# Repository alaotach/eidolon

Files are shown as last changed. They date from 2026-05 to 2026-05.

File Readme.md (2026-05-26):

# Euphoria

## Project Overview
Euphoria is a 3d holographic display for your setup and you can display whatever you want on it from anywhere in the world using the WiFi.

## Why I Built This
I was looking to build something, i searched for many ideas and I had liked a women safety device at first but that didn't make some sense so i started looking again and then i found something on my youtube recommendation it was titled "real holographic displays" and it showed a similar holographic display using the pepper's ghost technique and I really liked the idea and I wanted it on my desk too so i started building it immediately.

EUPHORIA-zine

## What's Inside This Folder
**PCB & Hardware Files:**
- `hardware/gerbers/` - All Gerber files for PCB manufacturing (e.g., `hologram-F_Cu.gbr`, `hologram-B_Cu.gbr`, etc.)
- `hardware/pcbs/hologram.kicad_pcb` - The main PCB layout file.
Screenshot_2026-05-20_085501-removebg-preview

- `hardware/pcbs/hologram.kicad_sch` - The main schematic.
- `hardware/pcbs/hologram.kicad_pro` - KiCad project file for editing.
- `hardware/fab/outputs/3d/updated-pcb.stl` - 3D model of the PCB.
PCB-F
PCB-B

**Firmware:**
  - `firmware/eidolon/` - All firmware source code.
	- `include/` - Header files.
**3D Case Files:**
- `hardware/fab/outputs/3d/updated-pcb.f3d` - 3D models for the PCB.
- `hardware/fab/outputs/3d/eldolon-case.stl` - 3D model of the case.
case
case1

**Misc Files:**
- `hardware/fab/outputs/bom/BOM.csv` - BOM.

## The Files You Actually Need
**To Manufacture the PCB:**
1. `hardware/pcbs/hologram.kicad_pcb`.
2. `hardware/gerbers/` - for PCB fabrication.
3. `hardware/pcbs/hologram.kicad_sch` - main schematic.

---

## Build Guide

### Step 1 - Export Gerbers from KiCad
Open `hologram.kicad_pcb` in KiCad, then generate gerbers and drill files. Zip all outputs together.

---

### Step 2 - Order the PCB
Upload your gerber zip to jlcpcb and place your order.

---

### Step 3 - Solder the leftover parts

- Battery connector
- Speaker connector
- Microphone connector
- Oled connector

---

### Step 4 - Connect the Battery
Use a flat LiPo battery with a 2-pin JST PH2.0 connector.

---

### Step 5 - Connect the Display
Connect the 1.3 inch 4 pin Oled display module.
---

### Step 6 - Flash the Firmware
- Use PlatformIO to flash the firmware in the ESP32-C3-WROOM-02

---

### Step 7 - 3D Print
- **Material:** PLA works.
---

### Step 9 - Assemble the Pyramid
Cut your transparent acrylic sheet into 4 identical trapezoid pieces and place them accordingly.
---

### Modifying the Firmware
- All main configs are in `include/Config.h`.
- Each feature is in its own file.
---

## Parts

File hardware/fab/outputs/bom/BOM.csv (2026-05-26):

Reference | Qty | Value | Footprint | Datasheet | Price Per Piece | Total Price | URL
C1,C2,C3,C4,C5 | 5 | C | Capacitor_THT:C_Rect_L4.6mm_W2.0mm_P2.50mm_MKS02_FKP02
J1 | 1 | Oled conn | 1.3 inch I2C OLED Display Module 4pin |  | 2.82 | 2.82 | https://robocraze.com/products/1-3in-oled-display?variant=40192586842265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
J2 | 1 | Battery | WLY803040 3.7V 1000mAh 1S LiPo Battery |  | 3.95 | 3.95 | https://robu.in/product/wly803040-1000mah-3-7v-single-cell-rechargeable-lipo-battery/
J3 | 1 | INMP441 | INMP441 MEMS |  | 1.53 | 1.53 | https://robocraze.com/products/inmp441-mems-high-precision-omnidirectional-microphone-module-i2s
J4 | 1 | Speaker | Electronic Spices 2 Inch 4Ω (ohm) 5W |  | 1.5 | 1.5 | https://www.amazon.in/Electronic-Spices-Power-Woofer-Speaker/dp/B0BN44HPF9?s=electronics
J6 | 1 | MPU6050 | Connector_PinHeader_2.54mm:PinHeader_1x08_P2.54mm_Horizontal |  | 1.77 | 1.77 | https://robu.in/product/mpu-6050-gyro-sensor-2-accelerometer/
P1 | 1 | USB_C_Plug_USB2.0 | Connector_USB:USB_C_Receptacle_HRO_TYPE-C-31-M-12 | https://www.usb.org/sites/default/files/documents/usb_type-c.zip
R1,R2,R3 | 3 | R | Resistor_THT:R_Axial_DIN0204_L3.6mm_D1.6mm_P7.62mm_Horizontal
SW1 | 1 | SW_MEC_5E | Button_Switch_SMD:SW_MEC_5GSH9 | https://www.apem.com/medias/download/MEC_switches_serie_MULTIMEC5E.pdf
U1 | 1 | BQ24074RGT | Package_DFN_QFN:VQFN-16-1EP_3x3mm_P0.5mm_EP1.6x1.6mm | http://www.ti.com/lit/ds/symlink/bq24074.pdf | 2.86 | 2.86 | https://www.digikey.in/en/products/detail/texas-instruments/BQ24074RGTT/1957746
U2 | 1 | ESP32-C3-WROOM-02 | RF_Module:ESP32-C3-WROOM-02 | https://www.espressif.com/sites/default/files/documentation/esp32-c3-wroom-02_datasheet_en.pdf | 2.1 | 2.1 | https://www.electropi.in/espressif-esp32-c3-wroom-02-n4-module
U3 | 1 | AP2112K-3.3 | Package_TO_SOT_SMD:SOT-23-5 | https://www.diodes.com/assets/Datasheets/AP2112.pdf | 0.26 | 0.26 | https://robu.in/product/ap2112k-1-8trg1-diodes-incorporated-65db1khz-600ma-fixed-1-8v-positive-6v-sot-25-voltage-regulators-linear-low-drop-out-ldo-regulators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
U4 | 1 | MAX98357A | Package_DFN_QFN:TQFN-16-1EP_3x3mm_P0.5mm_EP1.23x1.23mm | https://www.analog.com/media/en/technical-documentation/data-sheets/MAX98357A-MAX98357B.pdf | 1.2 | 1.2 | https://robokits.co.in/sensors/sound/max98357-i2s-3w-class-d-amplifier-interface-audio-decoder-module-filterless-board-for-raspberry-pi-esp32
 |  |  |  |  |  | 17.99

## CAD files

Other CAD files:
hardware/fab/outputs/3d/updated-pcb.f3d

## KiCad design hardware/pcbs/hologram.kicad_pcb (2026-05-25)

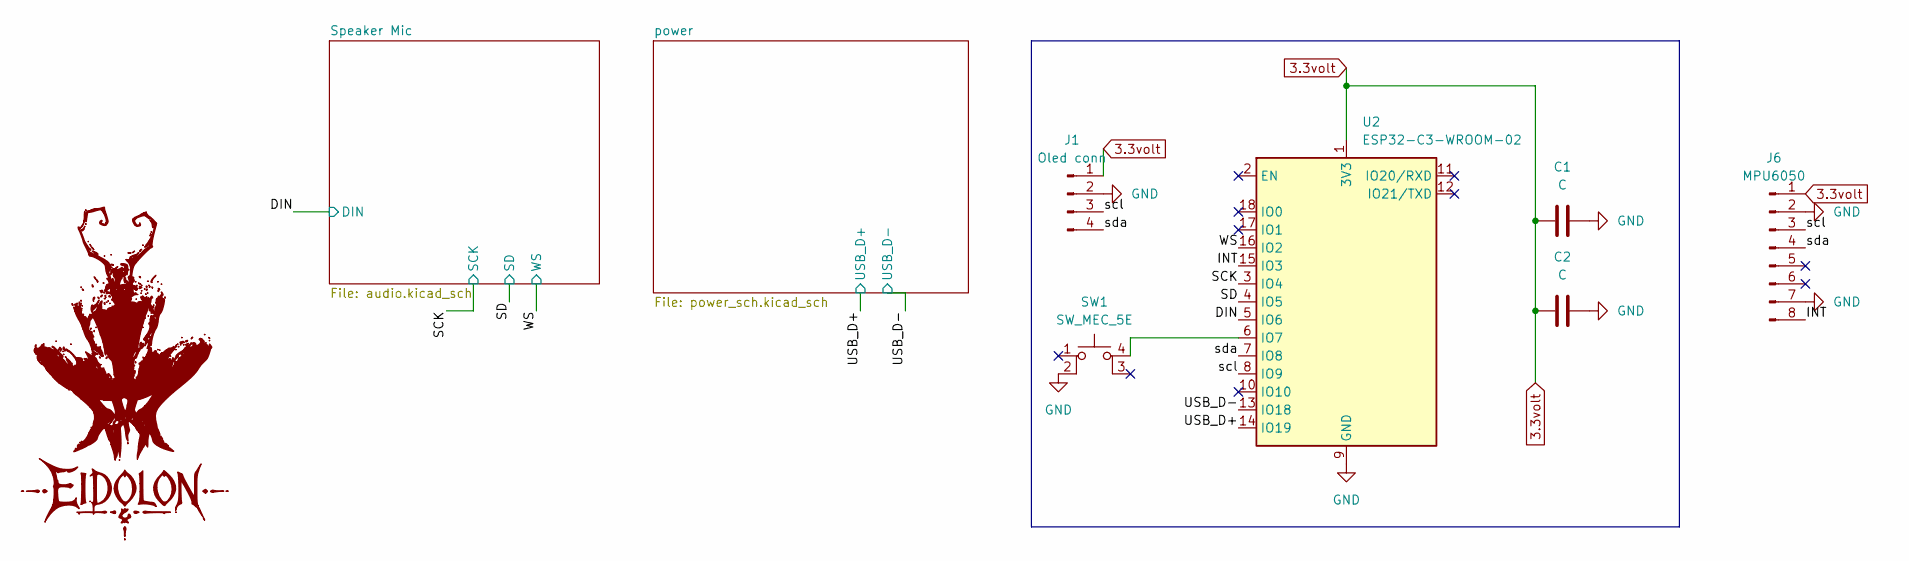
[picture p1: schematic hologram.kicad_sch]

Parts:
C1, C2: C; C_Rect_L4.6mm_W2.0mm_P2.50mm_MKS02_FKP02
J1: Oled conn; PinHeader_1x04_P2.54mm_Horizontal
J6: MPU6050; PinHeader_1x08_P2.54mm_Horizontal
SW1: SW_MEC_5E; SW_MEC_5GSH9
U2: ESP32-C3-WROOM-02

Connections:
3.3volt: C1.1, C2.1, J1.1, J6.1, U2.1 (3V3); also elsewhere on the board
/DIN: U2.5 (IO6); also elsewhere on the board
/INT: J6.8, U2.15 (IO3)
/SCK: U2.3 (IO4); also elsewhere on the board
/SD: U2.4 (IO5); also elsewhere on the board
/USB_D+: U2.14 (IO19); also elsewhere on the board
/USB_D-: U2.13 (IO18); also elsewhere on the board
/WS: U2.16 (IO2); also elsewhere on the board
/scl: J1.3, J6.3, U2.8 (IO9)
/sda: J1.4, J6.4, U2.7 (IO8)
GND: C1.2, C2.2, J1.2, J6.2, J6.7, SW1.2, U2.9 (GND), U2.19 (GND); also elsewhere on the board
unnamed: SW1.4 (A), U2.6 (IO7)

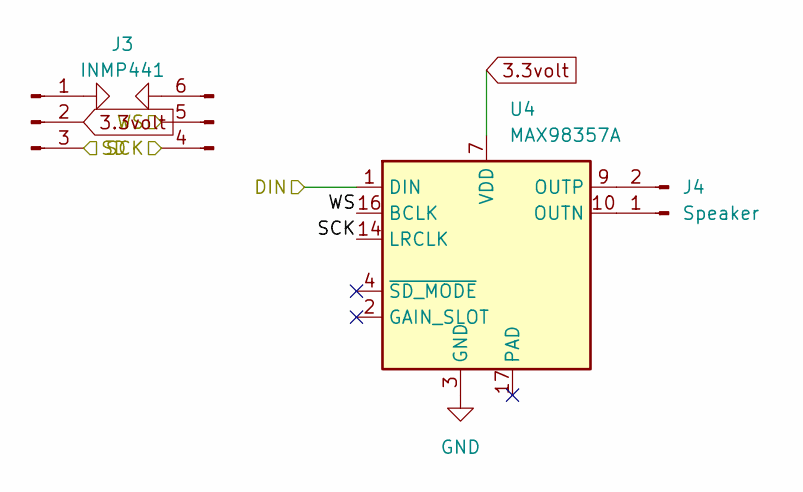
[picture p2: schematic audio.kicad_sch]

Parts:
J3: INMP441; PinHeader_1x06_P2.54mm_Horizontal
J4: Speaker; PinHeader_1x02_P2.54mm_Horizontal
U4: MAX98357A; TQFN-16-1EP_3x3mm_P0.5mm_EP1.23x1.23mm

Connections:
3.3volt: J3.2, U4.7 (VDD), U4.8 (VDD); also elsewhere on the board
/DIN: U4.1 (DIN); also elsewhere on the board
/SCK: J3.4, U4.14 (LRCLK); also elsewhere on the board
/SD: J3.3; also elsewhere on the board
/WS: J3.5, U4.16 (BCLK); also elsewhere on the board
GND: J3.1, J3.6, U4.3 (GND), U4.11 (GND), U4.15 (GND); also elsewhere on the board
unnamed: J4.1, U4.10 (OUTN)
unnamed: J4.2, U4.9 (OUTP)

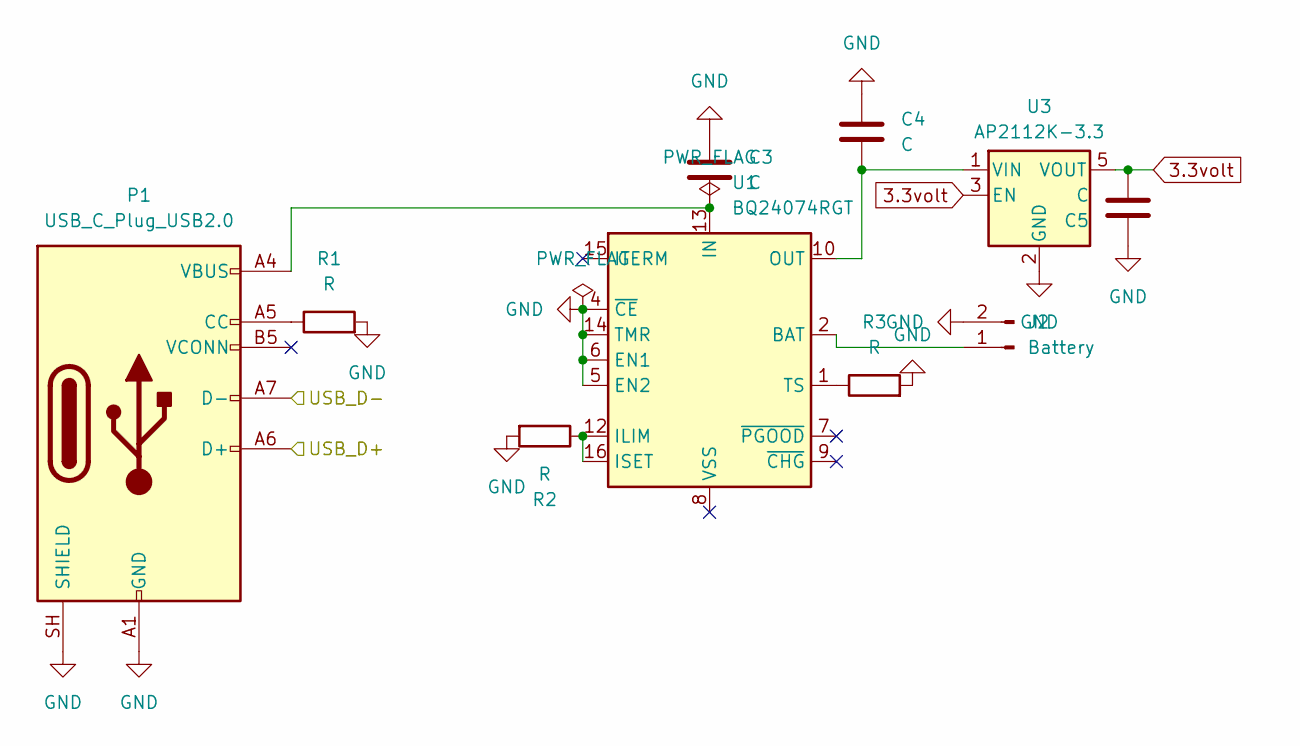
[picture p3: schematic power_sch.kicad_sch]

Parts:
C3, C4, C5: C; C_Rect_L4.6mm_W2.0mm_P2.50mm_MKS02_FKP02
J2: Battery; PinHeader_1x02_P2.54mm_Horizontal
P1: USB_C_Plug_USB2.0; USB_C_Receptacle_HRO_TYPE-C-31-M-12
R1, R2, R3: R; R_Axial_DIN0204_L3.6mm_D1.6mm_P7.62mm_Horizontal
U1: BQ24074RGT; VQFN-16-1EP_3x3mm_P0.5mm_EP1.6x1.6mm
U3: AP2112K-3.3; SOT-23-5

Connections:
3.3volt: C5.2, U3.3 (EN), U3.5 (VOUT); also elsewhere on the board
/USB_D+: P1.A6 (D+); also elsewhere on the board
/USB_D-: P1.A7 (D-); also elsewhere on the board
GND: C3.1, C4.1, C5.1, J2.2, P1.A1 (GND), P1.A12 (GND), P1.B1 (GND), P1.B12 (GND), P1.SH (SHIELD), R1.2, R2.2, R3.2, U1.4 (~CE), U1.5 (EN2), U1.6 (EN1), U1.14 (TMR), U3.2 (GND); also elsewhere on the board
unnamed: J2.1, U1.2 (BAT), U1.3 (BAT)
unnamed: P1.A5 (CC), R1.1
unnamed: R2.1, U1.12 (ILIM), U1.16 (ISET)
unnamed: C3.2, P1.A4 (VBUS), P1.A9 (VBUS), P1.B4 (VBUS), P1.B9 (VBUS), U1.13 (IN)
unnamed: R3.1, U1.1 (TS)
unnamed: C4.2, U1.10 (OUT), U1.11 (OUT), U3.1 (VIN)

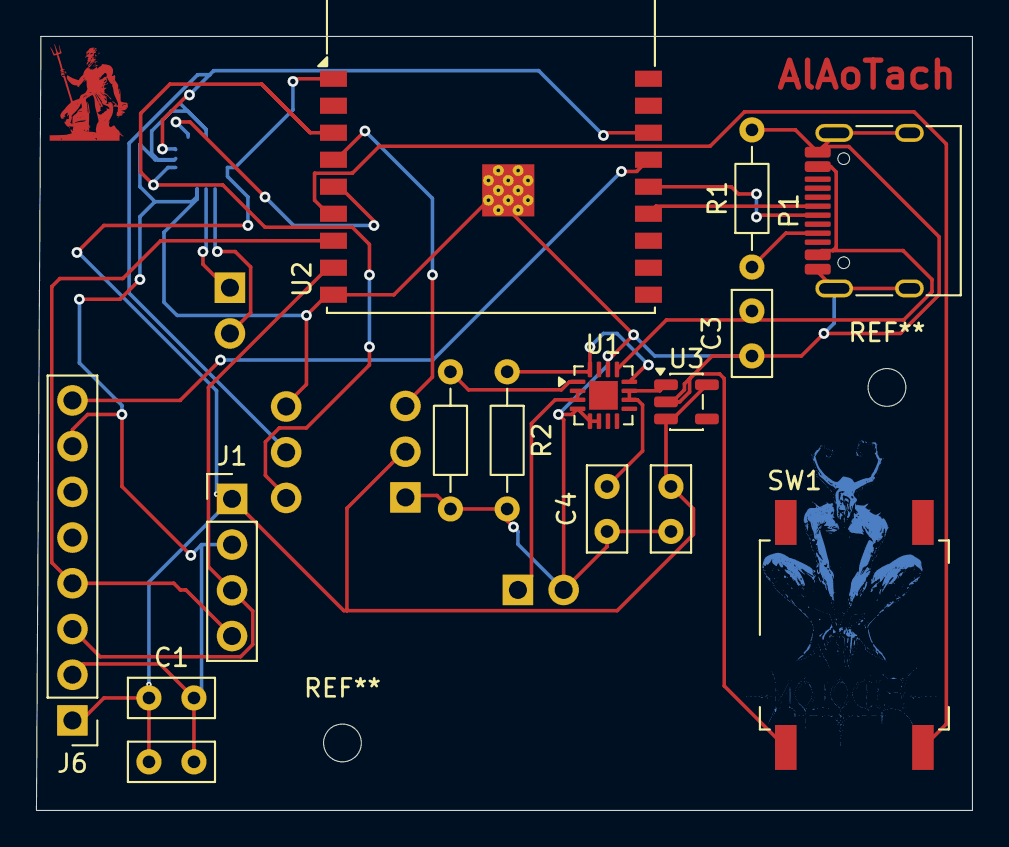
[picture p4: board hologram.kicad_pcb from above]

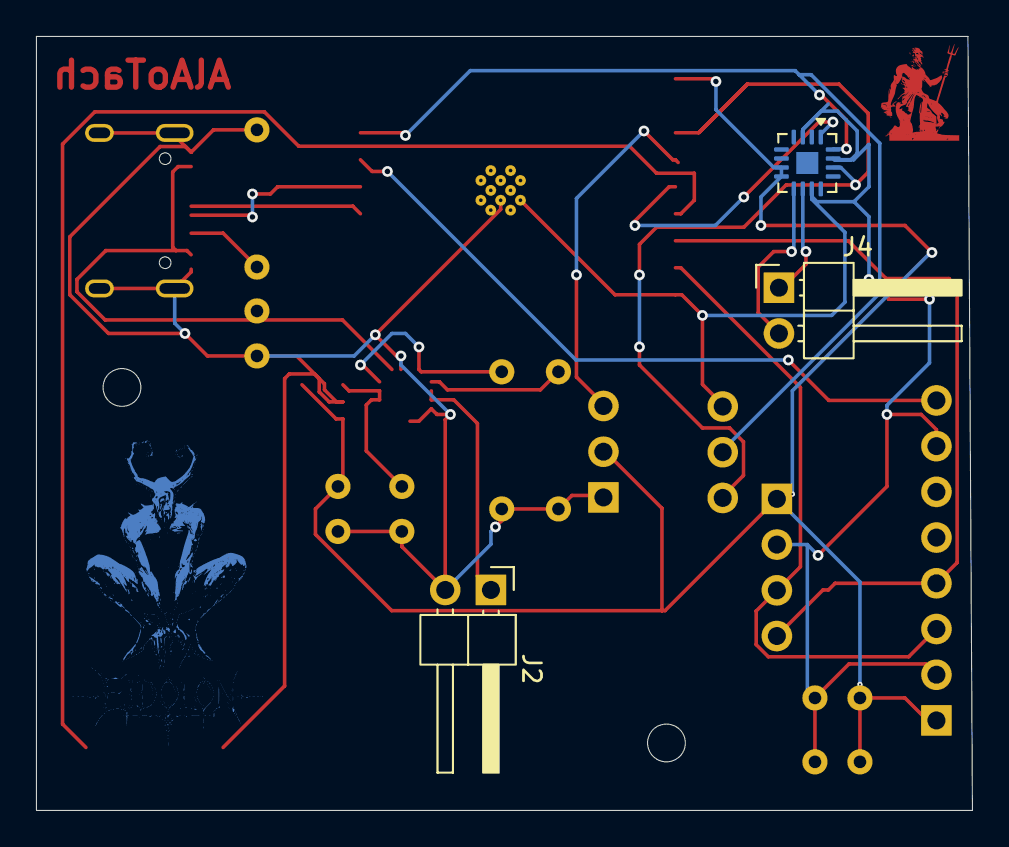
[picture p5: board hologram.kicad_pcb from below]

Board: 2 copper layers, 52.0 x 43.0 mm, 19 parts (3 on the bottom side), 20 nets.

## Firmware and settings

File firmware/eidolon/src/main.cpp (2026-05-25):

#include <Arduino.h>
#include "Config.h"
#include "I2c.h"
#include "I2S.h"
#include "LittleFSM.h"
#include "OLED.h"
#include "IMU.h"
#include "MEDIA.h"
#include "ImageRender.h"
#include "WiFiM.h"
#include "WebM.h"

void bootAnim();
void updateIMU();

void setup() {
  Serial.begin(1120000);
  delay(100);
  I2c::init();
  LittleFSM::init();
  I2S::init();
  MediaManager::init();
  if (WiFiM::init()) {
    WebM::init();
    WiFiM::getIP().toString();
  }
  bootAnim();
}

void loop() {
  WebM::handle();
  updateIMU();
}

void updateIMU() {
  uint32_t now = millis();
  if (IMU::getGyroX) {
    IMU::update();
  }
}

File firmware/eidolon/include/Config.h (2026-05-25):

#ifndef CONFIG_H
#define CONFIG_H

#define SSID "Eidolon"
#define PASSWORD "3.14159265"
#define CHANNEL 1
#define MAX_CONNECTIONS 4
#define SERVER_PORT 80

#define UPLOAD_DIR "/uploads"

#define SCREEN_WIDTH 128
#define SCREEN_HEIGHT 64
#define OLED_RESET -1
#define OLED_ADDRESS 0x3C

#define I2S_WS 2
#define I2S_SCK 4
#define I2S_SD 5
#define I2S_DIN 6

#define BUTTON_PIN 7

#define MPU_INT 3
#define MPU_ADDR 0x68

#define OLED_BRIGHTNESS 255
#define OLED_SCL 9
#define OLED_SDA 8


#endif

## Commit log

2026-05-25 initial commit and config of pins from schema
    [audio.kicad_sch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]
2026-05-25 littlefs,i2s, i2c done
2026-05-25 imu setup
2026-05-26 files organized
    [audio.kicad_sch, hologram-BOM.xlsx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]
